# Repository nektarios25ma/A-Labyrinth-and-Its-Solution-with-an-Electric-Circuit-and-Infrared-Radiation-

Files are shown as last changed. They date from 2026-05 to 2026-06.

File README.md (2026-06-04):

# A-Labyrinth-and-Its-Solution-with-an-Electric-Circuit-and-Infrared-Radiation-
A Labyrinth and Its Solution (with an Electric Circuit and Infrared Radiation)

Τίτλος έργου: Ένας Λαβύρινθος και η Λύση του (με Ηλεκτρικό Κύκλωμα και Υπέρυθρη Ακτινοβολία)

Ενα έργο που οπτικοποιεί τις ιδιότητες του ηλεκτρικού ρεύματος , διασκεδάζει και μαθαίνει τα παιδιά.

Θα μπορούσε μια κάμερα υπερύθρων να βρει τη λύση όταν οι διαδρομές του λαβυρίνθου είναι κατασκευασμένες από αγώγιμο σύρμα; 
Θα μπορούσε το ηλεκτρικό ρεύμα να «πηδήξει» σε ένα σπασμένο κύκλωμα - ή να ανιχνευθεί στην άλλη πλευρά του λαβυρίνθου;
Αυτά και άλλα ερωτήματα εξερευνώνται παιχνιδιάρικα με την κατασκευή μας.
Παρουσιάζουμε μια συσκευή χαμηλού κόστους για τη διδασκαλία βασικών εννοιών στον Ηλεκτρομαγνητισμό και την Ανάλυση Κυκλωμάτων, σχεδιασμένη ως μικροσκοπικός λαβύρινθος (23×23 cm).
Η διαδρομή θα είναι κατασκευασμένη από σύρμα νικελίου (NiCr) με συνολική αντίσταση ~22 Ω. Με τροφοδοσία 20 V DC, η ισχύς Joule P=V²/R≈18 W αναπτύσσεται κατά μήκος του σύρματος, παράγωντας μια μετρήσιμη αύξηση της θερμοκρασίας.
Η «σωστή» διαδρομή γίνεται ορατή σε πραγματικό χρόνο μέσω μιας υπέρυθρης κάμερας/θερμικής απεικόνισης ή/και ενός αισθητήρα υπερύθρων, παρέχοντας ένα ζωντανό οπτικό ανάλογο της ροής ρεύματος.
Ενσωματώνοντας μικροσκοπικά βολτόμετρα πάνελ σε επιλεγμένα τμήματα, οι μαθητές εξερευνούν πειραματικά τον κανόνα του βρόχου του Kirchhoff συγκρίνοντας το αλγεβρικό άθροισμα των αυξήσεων και των πτώσεων τάσης γύρω από κλειστούς βρόχους. 
Η δραστηριότητα ακολουθεί μια προσέγγιση βασισμένη στην έρευνα, παραθέτει σαφείς μαθησιακούς στόχους (Ohm, Joule, συντονισμός LC, αμοιβαία επαγωγή), περιλαμβάνει ένα σχέδιο ασφάλειας, έναν προϋπολογισμό υλικών κάτω των 80 € και κλίμακες διδακτικής αξίας από κατώτερη έως ανώτερη δευτεροβάθμια εκπαίδευση. Προτείνονται φύλλα εργασίας και διαμορφωτική αξιολόγηση. Η κατασκευή είναι αναπαράξιμη από κοινά μέρη και ταιριάζει με την θεματολογία των STEM .

ΒΙΝΤΕΟ ΕΞΗΓΗΣΗΣ : https://drive.google.com/file/d/1ATEh41-nR6oQ1FFbkLTpuzxIQqOrLd2V/view?usp=sharing

Λίστα υλικών :

1)Stereo Digital Audio Amplifier Module 2X50W – TPA3116 = €16,80

2)Καλώδιο Ήχου Jack σε Jack 3.5mm 1.5m  =€1,40 

3) 3 X   eSUN PLA Basic 1.75mm 1kg – Blue = 3X €15,90

4) ΚΑΛΩΔΙΑ ΚΤΛ =15 €

5)esp32 mcu = 10 €

ΣΥΝΟΛΟ = 90 €

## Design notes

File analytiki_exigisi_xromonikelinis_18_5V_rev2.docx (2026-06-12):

Θερμοκρασία σύρματος χρωμονικελίνης 0,35 mm στα 18,5 V DC

Διάκριση μεταξύ σχολικής ύλης Β΄ Λυκείου και πλήρους επιστημονικής εξήγησης

Δεδομένα προβλήματος

Μέγεθος | Τιμή
Τάση τροφοδοσίας | V = 18,5 V DC
Μήκος σύρματος | L = 1,9 m
Διάμετρος σύρματος | d = 0,35 mm
Ακτίνα σύρματος | r = 0,175 mm
Πρακτική αντίσταση κυκλώματος | R ≈ 21 Ω
Συνθήκες | · στη κατασκευή υπάρχει και επαφή/γειτνίαση με PLA

# Μέρος 1 – Μόνο όσα στηρίζονται άμεσα στο σχολικό βιβλίο της Β΄ Λυκείου

Στόχος του μέρους αυτού: να ξεχωρίσουμε καθαρά τι επιτρέπεται να χρησιμοποιηθεί ως σχολική ύλη και τι είναι εξήγηση εκτός ύλης.

## 1.1 Τι δίνει το σχολικό βιβλίο

- Η αντίσταση ενός κυλινδρικού αγωγού δίνεται από τη σχέση R = ρ·l/S, όπου S είναι το εμβαδόν της διατομής. Το βιβλίο τονίζει επίσης ότι η αντίσταση εξαρτάται από τη θερμοκρασία του αγωγού.
- Για την ηλεκτρική ενέργεια: W = V·I·t.
- Για την ισχύ του ρεύματος σε αντιστάτη: P = V·I = I²·R = V²/R.
- Για το φαινόμενο Joule: Q = I²·R·t, αλλά ο νόμος διατυπώνεται για μεταλλικό αγωγό σταθερής θερμοκρασίας.
- Στις εργαστηριακές δραστηριότητες του βιβλίου εμφανίζεται και ο τύπος της θερμιδομετρίας Q = m·c·Δθ, για θέρμανση νερού από αντιστάτη.

## 1.2 Πώς υπολογίζεται σωστά η διατομή

Η διατομή του σύρματος είναι το εμβαδόν του κύκλου που φαίνεται αν κόψουμε κάθετα το σύρμα. Άρα πράγματι:

A = π·r²

και επειδή r = d/2, ισοδύναμα A = π·d²/4

Για d = 0,35 mm → r = 0,175 mm

A = π·(0,175 mm)² = 0.09621 mm² ≈ 0,0962 mm²

Άρα η σωστή διατομή είναι 0,0962 mm². Συνήθη λάθη είναι:

- να μπει κατά λάθος d αντί για r στον τύπο π·r²,
- να ξεχαστεί ο παράγοντας 1/4 όταν γράφουμε τον τύπο με τη διάμετρο,
- να μπερδευτεί η διατομή με την εξωτερική επιφάνεια του σύρματος.

## 1.3 Τι μπορούμε να βρουμε μόνο με τη σχολική ύλη

1. I = V/R = 18,5/21 = 0.881 A
2. P = V·I = 18,5·0.881 = 16.30 W
3. ή ισοδύναμα P = V²/R = 18,5²/21 = 16.30 W

Συμπέρασμα σχολικής ύλης: το κύκλωμα διαρρέεται από ρεύμα περίπου 0,881 A και το σύρμα μετατρέπει ηλεκτρική ενέργεια σε θερμότητα με ρυθμό περίπου 16,3 W.

## 1.4 Τι δεν βγαίνει μόνο από τη σχολική ύλη

Η τελική θερμοκρασία του ίδιου του σύρματος δεν βρίσκεται μόνο από τους τύπους Q = I²Rt και Q = m·c·Δθ. Ο λόγος είναι ότι το σύρμα στον αέρα θερμαίνεται και ταυτόχρονα ψύχεται. Στη κατασκευή επιπλέον μεταφέρει θερμότητα και στο PLA. Άρα ένα μέρος της ηλεκτρικής ισχύος δεν μένει μέσα στο σύρμα.

Ποιοτική εξήγηση : η τελική θερμοκρασία προκύπτει όταν ισορροπήσουν η ηλεκτρική ισχύς που μπαίνει και οι θερμικές απώλειες προς αέρα, ακτινοβολία και πλαστικό. Επίσης, η θερμική κάμερα σε πολύ λεπτό σύρμα δείχνει συχνά φαινόμενη θερμοκρασία μικρότερη από την πραγματική θερμοκρασία του μετάλλου.

# Μέρος 2 – Πλήρης επιστημονική εξήγηση, βήμα προς βήμα

Στο μέρος αυτό χρησιμοποιούνται και έννοιες εκτός της στενής σχολικής ύλης: μάζα του σύρματος, ειδική θερμότητα κράματος NiCr, απώλειες προς τον αέρα, θερμική ακτινοβολία και μεταφορά θερμότητας προς το PLA.

## 2.1 Γεωμετρία του σύρματος

4. Διάμετρος: d = 0.35 mm = 0,00035 m
5. Ακτίνα: r = d/2 = 0.175 mm
6. Διατομή: A = π·r² = 0.09621 mm² = 9.621e-08 m²
7. Μήκος: L = 1.9 m
8. Εξωτερική επιφάνεια προς αέρα (αν είναι ελεύθερο): S = π·d·L = 0.002089 m² = 20.89 cm²

## 2.2 Ηλεκτρικά μεγέθη στα 18,5 V

9. Αντίσταση: R ≈ 21 Ω
10. Ρεύμα: I = V/R = 18,5/21 = 0.881 A
11. Ισχύς: P = V·I = 16.30 W
12. Άρα κάθε δευτερόλεπτο το σύρμα παίρνει περίπου 16.30 J ηλεκτρικής ενέργειας.

## 2.3 Τι δίνει ο συνδυασμός Q = m·c·Δθ και Q = I²·R·t

Για να χρησιμοποιηθεί ο τύπος Q = m·c·Δθ πρέπει πρώτα να βρούμε τη μάζα του σύρματος.

13. Όγκος σύρματος: Vολ = A·L = 9.621e-08·1,9 = 1.828 e-07 m³
14. Με πυκνότητα περίπου 8400 kg/m³, μάζα: m = ρ·Vολ ≈ 0.001536 kg = 1.536 g
15. Με ειδική θερμότητα περίπου c ≈ 450 J/(kg·°C), η θερμοχωρητικότητα είναι m·c ≈ 0.691 J/°C
16. Αν αγνοηθούν όλες οι απώλειες, τότε I²Rt = m·c·Δθ
17. Άρα ο αρχικός ρυθμός ανόδου θερμοκρασίας είναι περίπου dT/dt = P/(m·c) = 16.30/0.691 = 23.6 °C/s

Άρα ναι, οι τύποι Q = m·c·Δθ και Q = I²·R·t ισχύουν, αλλά δίνουν σωστά μόνο την αρχική θέρμανση ή την αδιαβατική προσέγγιση. Δεν δίνουν μόνοι τους την τελική θερμοκρασία λειτουργίας στον αέρα.

## 2.4 Γιατί δεν αρκεί το Q = m·c·Δθ για την τελική θερμοκρασία

Στην πράξη η σωστή εξίσωση είναι ενεργειακό ισοζύγιο:

ηλεκτρική ισχύς = απώλειες προς αέρα + απώλειες με ακτινοβολία + απώλειες προς PLA

Pηλ = Pair + Prad + PPLA

Η τελική θερμοκρασία προκύπτει όταν πάψει να αυξάνεται η θερμοκρασία, δηλαδή όταν η ισχύς που μπαίνει γίνει ίση με την ισχύ που φεύγει.

## 2.5 Ιδανική εκτίμηση για ελεύθερο, ίσιο σύρμα στον ήρεμο αέρα

Για ένα λεπτό σύρμα στον ήρεμο αέρα μπορούμε να χρησιμοποιήσουμε ένα απλό μοντέλο φυσικής συναγωγής και ακτινοβολίας. Με μια τυπική αποτελεσματική τιμή συναγωγής h ≈ 80 W/(m²·K) και εκπεμψιμότητα περίπου ε ≈ 0,88, δοκιμάζουμε θερμοκρασίες μέχρι να έχουμε ισορροπία.

18. Δοκιμή στους 109 °C με αέρα 20 °C
19. Pair = h·S·(Tw - Ta) = 80·0.002089·(109-20) = 14.87 W
20. Prad ≈ 1.45 W
21. Συνολικές απώλειες ≈ 16.33 W, πολύ κοντά στην ηλεκτρική ισχύ 16.30 W

Άρα η ελεύθερη-στον-αέρα εκτίμηση δίνει περίπου T ≈ 105–110 °C. Αυτή η τιμή αναφέρεται σε σύρμα που δεν χάνει αισθητή θερμότητα σε πλαστικό ή στηρίγματα.

## 2.6 Τι αλλάζει στη κατασκευή με PLA

Από τη θερμική εικόνα της κατασκευής :

22. Θερμοκρασία περιβάλλοντος περίπου 19.9 °C κατά την διεξαγωγή του πειράματος
23. Μέγιστη φαινόμενη ένδειξη θερμικής κάμερας περίπου 74.1 °C
24. Κεντρική περιοχή PLA περίπου 21.5 °C

Η εικόνα δείχνει ότι το PLA θερμαίνεται κατά μήκος της διαδρομής του σύρματος. Αυτό σημαίνει ότι μέρος της ισχύος φεύγει από το σύρμα προς το πλαστικό.

Αν πάρουμε ως πρώτο προσεγγιστικό έλεγχο την ένδειξη 74,1 °C, τότε οι απώλειες προς αέρα και ακτινοβολία είναι περίπου:

25. Pair ≈ 9.06 W
26. Prad ≈ 0.75 W
27. Άρα Pair + Prad ≈ 9.81 W
28. Εφόσον η ηλεκτρική ισχύς είναι 16.30 W, απομένουν περίπου PPLA ≈ 6.49 W προς το PLA ή προς άλλα στερεά σημεία επαφής
29. Το ισοδύναμο αυτής της «διαρροής» είναι περίπου GPLA ≈ 0.123 W/K

Σημαντική προσοχή: η θερμική κάμερα πιθανότατα υποεκτιμά τη θερμοκρασία του ίδιου του σύρματος, επειδή το σύρμα είναι πολύ λεπτό (0,35 mm) και το pixel της κάμερας «βλέπει» μαζί σύρμα και PLA. Άρα το 74,1 °C είναι καλύτερα να θεωρείται φαινόμενη θερμοκρασία περιοχής και όχι βέβαιη θερμοκρασία του μετάλλου.

## 2.7 Τελικό καθαρό συμπέρασμα

30. Η διατομή υπολογίζεται σωστά με A = π·r² ή ισοδύναμα A = π·d²/4. Για d = 0,35 mm βρίσκουμε A = 0,0962 mm².
31. Με αντίσταση περίπου 21 Ω και τάση 18,5 V, το ρεύμα είναι περίπου 0,881 A και η ηλεκτρική ισχύς περίπου 16,3 W.
32. Οι τύποι Q = m·c·Δθ και Q = I²·R·t ισχύουν, αλλά μόνο για την αρχική θέρμανση ή όταν αγνοούνται οι απώλειες θερμότητας.
33. Για ελεύθερο, ίσιο σύρμα στον ήρεμο αέρα η τελική θερμοκρασία προσεγγίζεται γύρω στα 105–110 °C.
34. Στη πραγματική κατασκευή η θερμοκρασία πέφτει, επειδή η θερμότητα μοιράζεται σε αέρα, ακτινοβολία και PLA. Γι’ αυτό η μέτρηση είναι λογικό να βγαίνει χαμηλότερη από την ιδανική free-air εκτίμηση.
35. Με βάση τη θερμική εικόνα, μια ρεαλιστική περιοχή λειτουργίας είναι ότι η φαινόμενη ένδειξη της κάμερας είναι περίπου 74 °C, ενώ η πραγματική θερμοκρασία του σύρματος μπορεί να είναι λίγο υψηλότερη αλλά σαφώς χαμηλότερη από την ιδανική τιμή των 105–110 °C.

## Παράρτημα – Σύντομη αναφορά στο σχολικό βιβλίο

Το πρώτο μέρος βασίστηκε στα κεφάλαια «Αντίσταση (ωμική) – Αντιστάτης» και «Ενέργεια και ισχύς του ηλεκτρικού ρεύματος / Νόμος του Joule» του σχολικού βιβλίου: Φυσική Γενικής Παιδείας, Β΄ Γενικού Λυκείου, ΙΤΥΕ «Διόφαντος».

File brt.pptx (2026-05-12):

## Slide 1

ΤΙΤΛΟΣ ΕΡΓΑΣΙΑΣ
Η υπέρυθρη ακτινοβολία ως εργαλείο μελέτης κυκλωμάτων και άλλα εργαλεία ανάλυσης τους
ΓΕΛ ΝΕΑΣ ΚΥΔΩΝΙΑΣ

ΕΡΓΟ ΤΩΝ ΜΑΘΗΤΡΙΩΝ: ΤΡΟΥΛΑΚΗ ΑΝΘΗ , ΤΣΑΚΙΡΗ ΑΜΑΝΤΑ , ΧΑΛΙΒΕΛΑΚΗ ΗΛΕΚΤΡΑ , ΠΑΠΑΘΕΟΦΑΝΟΥΣ ΧΡΥΣΟΥΛΑ, ΠΛΑΤΣΑΚΗ ΠΑΝΑΓΙΩΤΑ,ΣΙΝΑΝΗ ΚΩΝΣΤΑΝΤΙΝΑ,ΣΙΝΑΝΙ ΕΙΡΗΝΗ,ΝΤΟΥΚΑΚΗ ΠΑΝΑΓΙΩΤΑ,ΒΟΜΒΟΛΑΚΗ ΕΛΕΝΗ=>ΟΜΑΔΑ ΛΑΒΥΡΙΝΘΟΣ

ΥΠΕΥΘΥΝΟΣ ΚΑΘΗΓΗΤΗΣ : ΚΟΥΡΑΚΗΣ ΝΕΚΤΑΡΙΟΣ

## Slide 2

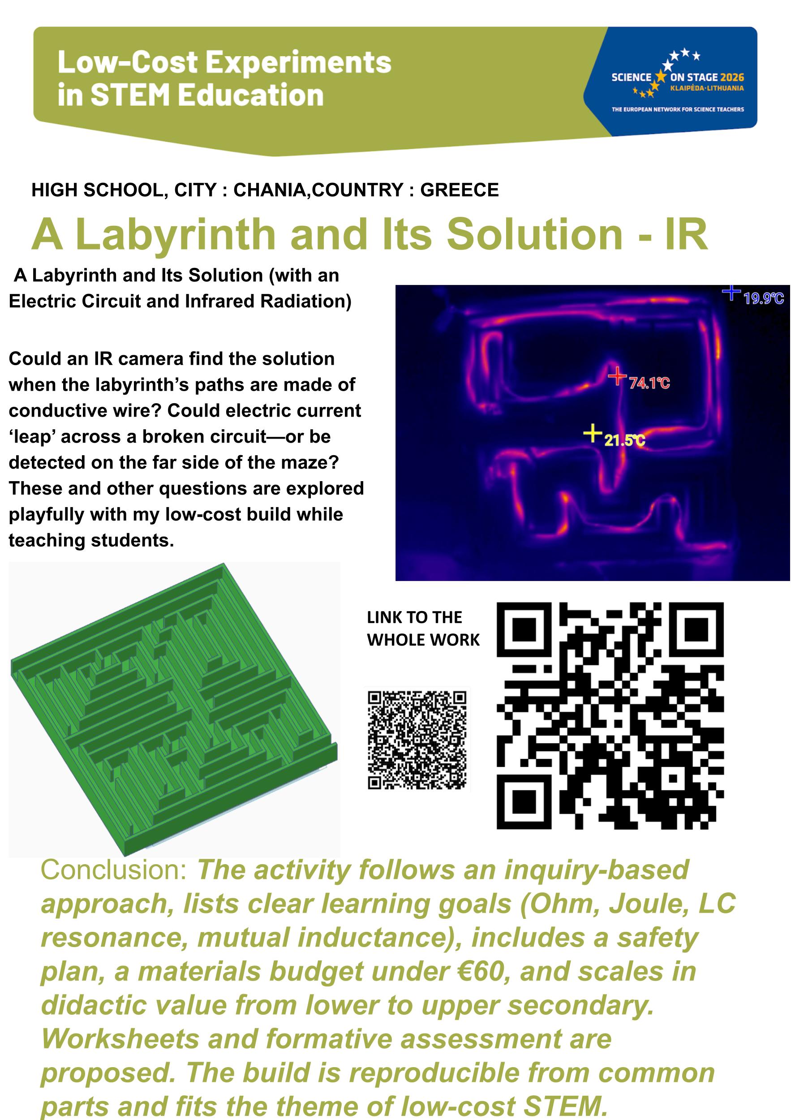
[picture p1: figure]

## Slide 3

Παρουσιάζεται μία κατασκευή χαμηλού κόστους για τη διδασκαλία βασικών εννοιών του Ηλεκτρομαγνητισμού και της Ανάλυσης Κυκλωμάτων, με τη μορφή μινιατούρας λαβυρίνθου (23×23 cm).

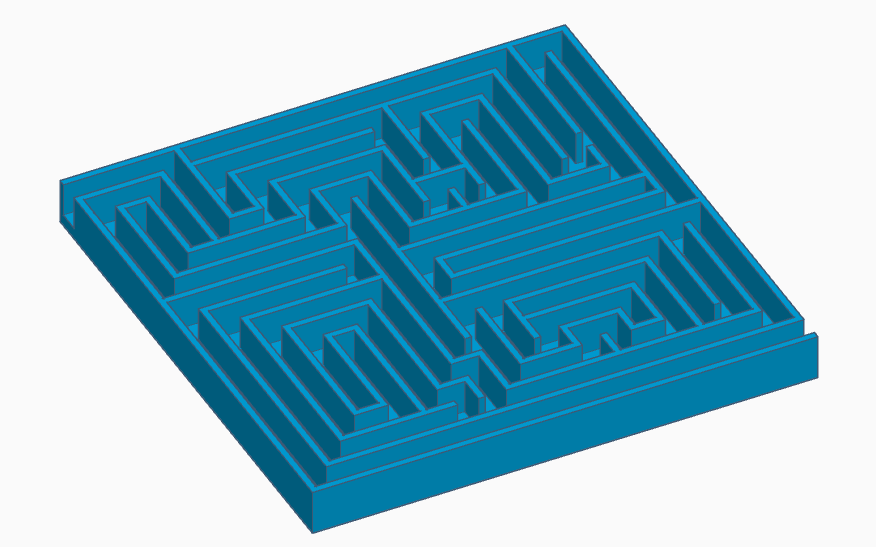
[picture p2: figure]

Η διαδρομή του λαβυρίνθου υλοποιείται - διακλαδώνεται με σύρμα χρωμονικελίνης (NiCr) συνολικής αντίστασης ~22 Ω. Με τροφοδότηση συνεχούς τάσης 20 V αναπτύσσεται ισχύς Joule P=V²/R≈18 W πάνω στο σύρμα, με αποτέλεσμα μετρήσιμη αύξηση θερμοκρασίας.

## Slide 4

Η «σωστή» διαδρομή του λαβυρίνθου οπτικοποιείται σε πραγματικό χρόνο μέσω υπέρυθρης κάμερας/θερμογράφου ή/και αισθητήρα υπερύθρων, προσφέροντας ισχυρό οπτικό ανάλογο της ροής ρεύματος.

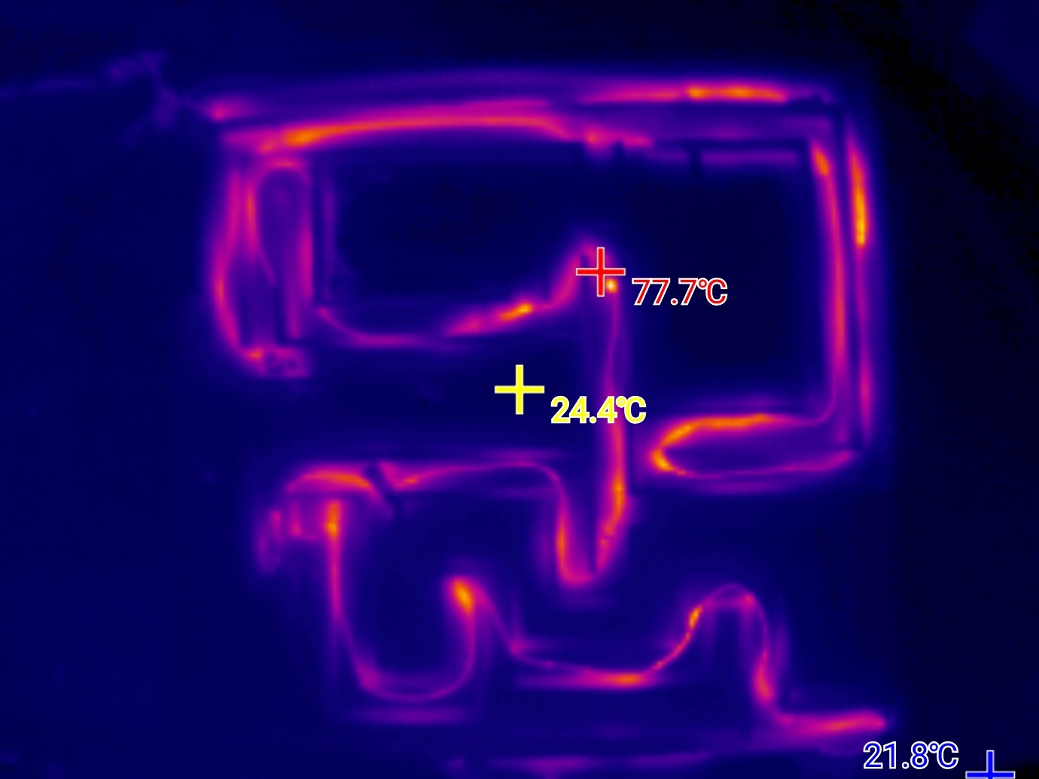
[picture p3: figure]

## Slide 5

2ο μέρος: Θα μπορούσε το ηλεκτρικό ρεύμα να υπερπηδήσει το εμπόδιο του αδιεξόδου; ΝΑΙ ΑΛΛΑ ΜΟΝΟ ΣΤΟ ΕΝΑΛΛΑΣΣΟΜΕΝΟ ΗΛΕΚΤΡΙΚΟ ΡΕΥΜΑ ΣΤΗΝ ΣΥΝΕΧΕΙΑ Ο ΤΡΟΠΟΣ

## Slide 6

Στη συνέχεια εισάγεται η έννοια της ηλεκτρομαγνητικής επαγωγής που εδώ ονομάζεται και αμοιβαία επαγωγή.

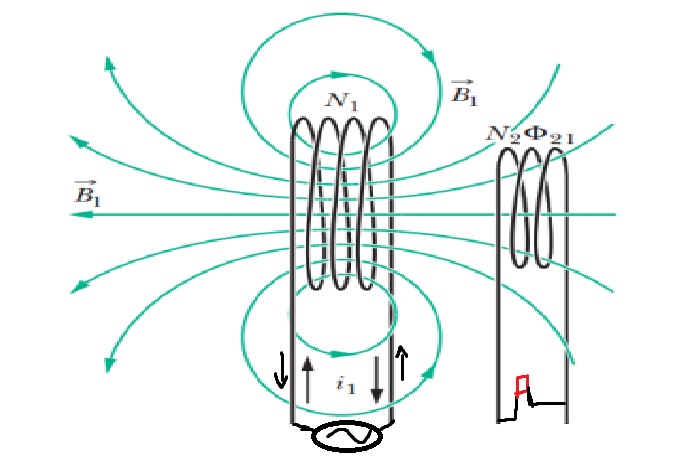
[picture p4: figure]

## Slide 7

Κύκλωμα LC

Η συχνότητα του εναλλασσόμενου ρεύματος που δημιουργείται όταν* δίνεται από την σχέση :

και η αντίστοιχη περίοδος :

*όλα λοιπον είναι θεμα χρόνου!

*Τότε έχουμε καλύτερη ανταπόκριση * =>φωτεινότητα led
συντονισμός

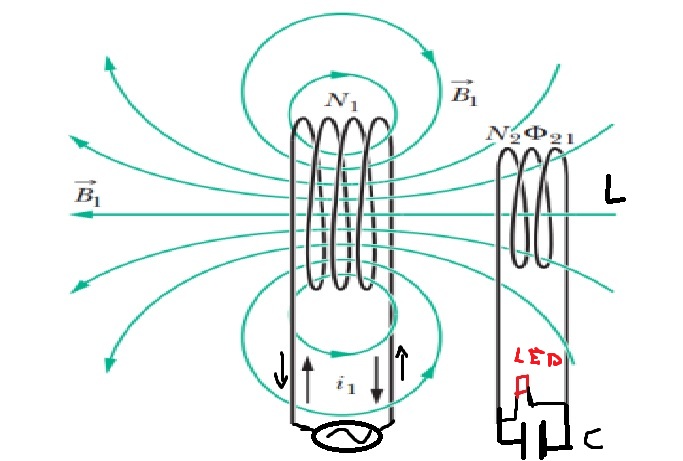
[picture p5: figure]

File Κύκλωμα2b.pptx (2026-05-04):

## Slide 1

ΤΙΤΛΟΣ ΕΡΓΑΣΙΑΣ
Η υπέρυθρη ακτινοβολία ως εργαλείο μελέτης κυκλωμάτων και άλλα εργαλεία ανάλυσης τους
ΓΕΛ ΝΕΑΣ ΚΥΔΩΝΙΑΣ

ΕΡΓΟ ΤΩΝ ΜΑΘΗΤΡΙΩΝ: ΤΡΟΥΛΑΚΗ ΑΝΘΗ , ΤΣΑΚΙΡΗ ΑΜΑΝΤΑ , ΧΑΛΙΒΕΛΑΚΗ ΗΛΕΚΤΡΑ , ΠΑΠΑΘΕΟΦΑΝΟΥΣ ΧΡΥΣΟΥΛΑ, ΠΛΑΤΣΑΚΗ ΠΑΝΑΓΙΩΤΑ ΚΑΙ ……………………….. =>ΟΜΑΔΑ ΛΑΒΥΡΙΝΘΟΣ

ΥΠΕΥΘΥΝΟΣ ΚΑΘΗΓΗΤΗΣ : ΚΟΥΡΑΚΗΣ ΝΕΚΤΑΡΙΟΣ

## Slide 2


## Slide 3

Παρουσιάζεται μία κατασκευή χαμηλού κόστους για τη διδασκαλία βασικών εννοιών του Ηλεκτρομαγνητισμού και της Ανάλυσης Κυκλωμάτων, με τη μορφή μινιατούρας λαβυρίνθου (23×23 cm).


Η διαδρομή του λαβυρίνθου υλοποιείται - διακλαδώνεται με σύρμα χρωμονικελίνης (NiCr) συνολικής αντίστασης ~22 Ω. Με τροφοδότηση συνεχούς τάσης 20 V αναπτύσσεται ισχύς Joule P=V²/R≈18 W πάνω στο σύρμα, με αποτέλεσμα μετρήσιμη αύξηση θερμοκρασίας.

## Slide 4

Η «σωστή» διαδρομή του λαβυρίνθου οπτικοποιείται σε πραγματικό χρόνο μέσω υπέρυθρης κάμερας/θερμογράφου ή/και αισθητήρα υπερύθρων, προσφέροντας ισχυρό οπτικό ανάλογο της ροής ρεύματος.


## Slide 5

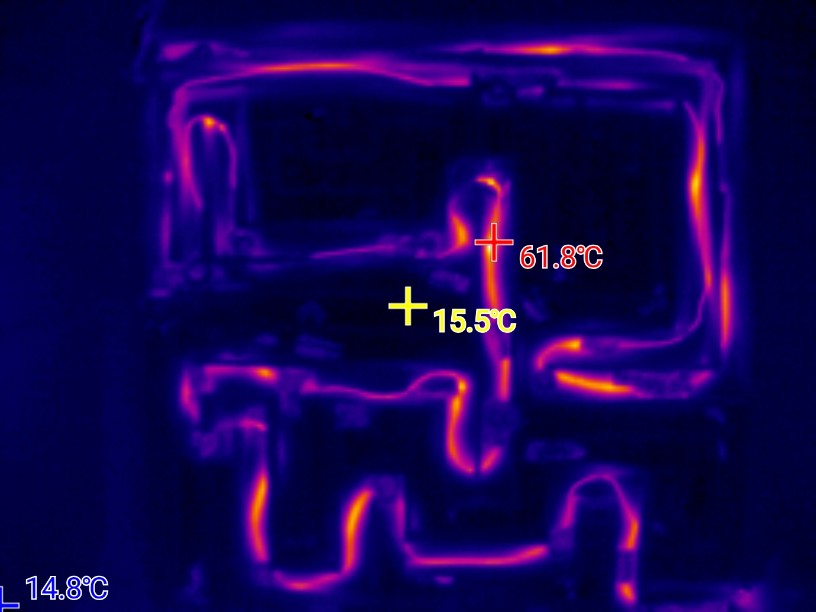
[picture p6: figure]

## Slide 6

2ο μέρος: Θα μπορούσε το ηλεκτρικό ρεύμα να υπερπηδήσει το εμπόδιο του αδιέξοδου; ΝΑΙ ΑΛΛΑ ΜΟΝΟ ΣΤΟ ΕΝΑΛΛΑΣΣΟΜΕΝΟ ΗΛΕΚΤΡΙΚΟ ΡΕΥΜΑ , ΣΤΗΝ ΣΥΝΕΧΕΙΑ Ο ΤΡΟΠΟΣ

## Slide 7

….και αυτό γινεται μέσω της αμοιβαίας επαγωγής.


Στην αμοιβαία επαγωγή έχουμε ασύρματη μεταφορά ενέργειας από το πρώτο πηνίο στο δεύτερο….

Εάν όμως αυτή η ασύρματη μεταφορά ενεργειας δεν επαρκεί για να ανάψει ένα λαμπάκι τότε:

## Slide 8

Λύση=>Κύκλωμα LC

Η συχνότητα του εναλλασσόμενου ρεύματος που δίνεται στο 1 ο όταν* δίνεται από την σχέση :

και η αντίστοιχη περίοδος :

*όλα λοιπον είναι θέμα χρόνου ή συντονισμού!

*Τότε έχουμε καλύτερη ανταπόκριση * =>φωτεινότητα led στο δεύτερο πηνίο


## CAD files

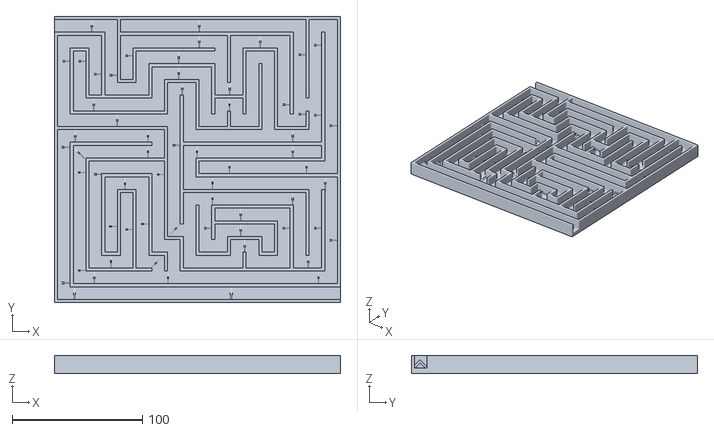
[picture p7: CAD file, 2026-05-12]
maze4 (2).stl
220.0 x 220.0 x 14.0

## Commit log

2026-01-30 Update README with project details and materials
    Added project description and material list in Greek.
2026-06-03 Add video explanation link and materials list
    Added a video link for explanation and updated materials list.
